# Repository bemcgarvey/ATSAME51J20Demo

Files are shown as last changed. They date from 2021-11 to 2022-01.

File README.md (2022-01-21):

# ATSAME51J20Demo
 
## A demonstartion board for the ATSAME51J20 microcontroller.  Includes firmware projects to demonstrate many modules and features.  
  
### There is sample firmware for:
* Basic gpio and interrupts
* Event system
* DMA
* Full speed USB
* SD Card
* USB bootloader and file system boot loader (sd card)
* USB CDC device
* and more

### All firmware is built in MPLabX with MPLab Harmony 3 and the XC32 compiler.  
### Schematic and PCB were made with KiCAD

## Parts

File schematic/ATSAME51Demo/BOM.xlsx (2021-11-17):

Reference | Quantity | Value | Footprint
C1 C4 C5 C6 C8 C10 C12 | 7 | 100n | Capacitor_SMD:C_0402_1005Metric
C11 | 1 | 4.7uF | Capacitor_SMD:C_0603_1608Metric
C15 | 1 | 10uF | Capacitor_SMD:C_0603_1608Metric
C14 C16 | 2 | 100n | Capacitor_SMD:C_0603_1608Metric
C17 | 1 | 220n | Capacitor_SMD:C_0603_1608Metric
C2 C3 | 2 | 20p | Capacitor_SMD:C_0603_1608Metric
C7 | 1 | 10uF | Capacitor_SMD:C_0805_2012Metric
C9 | 1 | 22uF | Capacitor_SMD:C_0603_1608Metric
D1 | 1 | Red | LED_SMD:LED_0603_1608Metric
D2 | 1 | Red | LED_SMD:LED_0805_2012Metric
D3 D4 | 2 | MBR0520LT | Diode_SMD:D_SOD-123
D5 | 1 | Yellow | LED_SMD:LED_0805_2012Metric
D6 | 1 | Blue | LED_SMD:LED_0805_2012Metric
D7 | 1 | Green | LED_SMD:LED_0805_2012Metric
D8 | 1 | Green | LED_SMD:LED_0603_1608Metric
D9 | 1 | Yellow | LED_SMD:LED_0603_1608Metric
IC1 | 1 | ATSAME51J20A-AU | SamacSys_Parts:QFP50P1200X1200X120-64N
IC2 | 1 | AZ1117IH-3.3TRG1 | SamacSys_Parts:SOT230P700X180-4N
IC3 | 1 | MCP2221-I_SL | SamacSys_Parts:SOIC127P600X175-14N
J1 | 1 | Barrel_Jack_Switch | Connector_BarrelJack:BarrelJack_Wuerth_6941xx301002
J10 J15 | 2 | Conn_02x06_Odd_Even | Connector_PinHeader_2.54mm:PinHeader_2x06_P2.54mm_Vertical
J11 J16 | 2 | Conn_02x07_Odd_Even | Connector_PinHeader_2.54mm:PinHeader_2x07_P2.54mm_Vertical
J13 | 1 | Conn_01x08 | Connector_PinHeader_2.54mm:PinHeader_1x08_P2.54mm_Horizontal
J14 | 1 | Conn_02x08_Odd_Even | Connector_PinHeader_2.54mm:PinHeader_2x08_P2.54mm_Vertical
J2 | 1 | Power | Connector_PinHeader_2.54mm:PinHeader_2x03_P2.54mm_Vertical
J3 J6 J12 J17 | 4 | Conn_01x02 | Connector_PinHeader_2.54mm:PinHeader_1x02_P2.54mm_Vertical
J4 | 1 | USB_B_Micro | Connector_USB:USB_Micro-B_Amphenol_10104110_Horizontal
J5 | 1 | USB_B_Mini | Connector_USB:USB_Mini-B_Wuerth_65100516121_Horizontal
J7 J8 | 2 | Conn_02x02_Odd_Even | Connector_PinHeader_2.54mm:PinHeader_2x02_P2.54mm_Vertical
J9 | 1 | Micro SD Card | SamacSys_Parts:MEM20750014001A
L1 | 1 | 470R | Inductor_SMD:L_0603_1608Metric
L2 | 1 | 10uH | Inductor_SMD:L_0603_1608Metric
R1 R9 R10 R12 R15 | 5 | 100k | Resistor_SMD:R_0603_1608Metric
R11 R14 | 2 | 4k7 | Resistor_SMD:R_0603_1608Metric
R13 R16 R17 R18 | 4 | 10k | Resistor_SMD:R_0603_1608Metric
R2 R5 R6 R8 R19 R20 | 6 | 220R | Resistor_SMD:R_0603_1608Metric
R3 | 1 | 15k | Resistor_SMD:R_0603_1608Metric
R4 | 1 | 22k | Resistor_SMD:R_0603_1608Metric
R7 | 1 | 62R | Resistor_SMD:R_0603_1608Metric
SW1 | 1 | SW_MEC_5E | SamacSys_Parts:PTS647SK38SMTR2LFS
SW2 SW3 | 2 | SW_MEC_5E | SamacSys_Parts:FSM16JH
X1 | 1 | 12 MHz | SamacSys_Parts:ASTMUPCE3312000MHZLJET
X2 | 1 | 32.768 kHz 12.5 pF | SamacSys_Parts:CM9VT1A

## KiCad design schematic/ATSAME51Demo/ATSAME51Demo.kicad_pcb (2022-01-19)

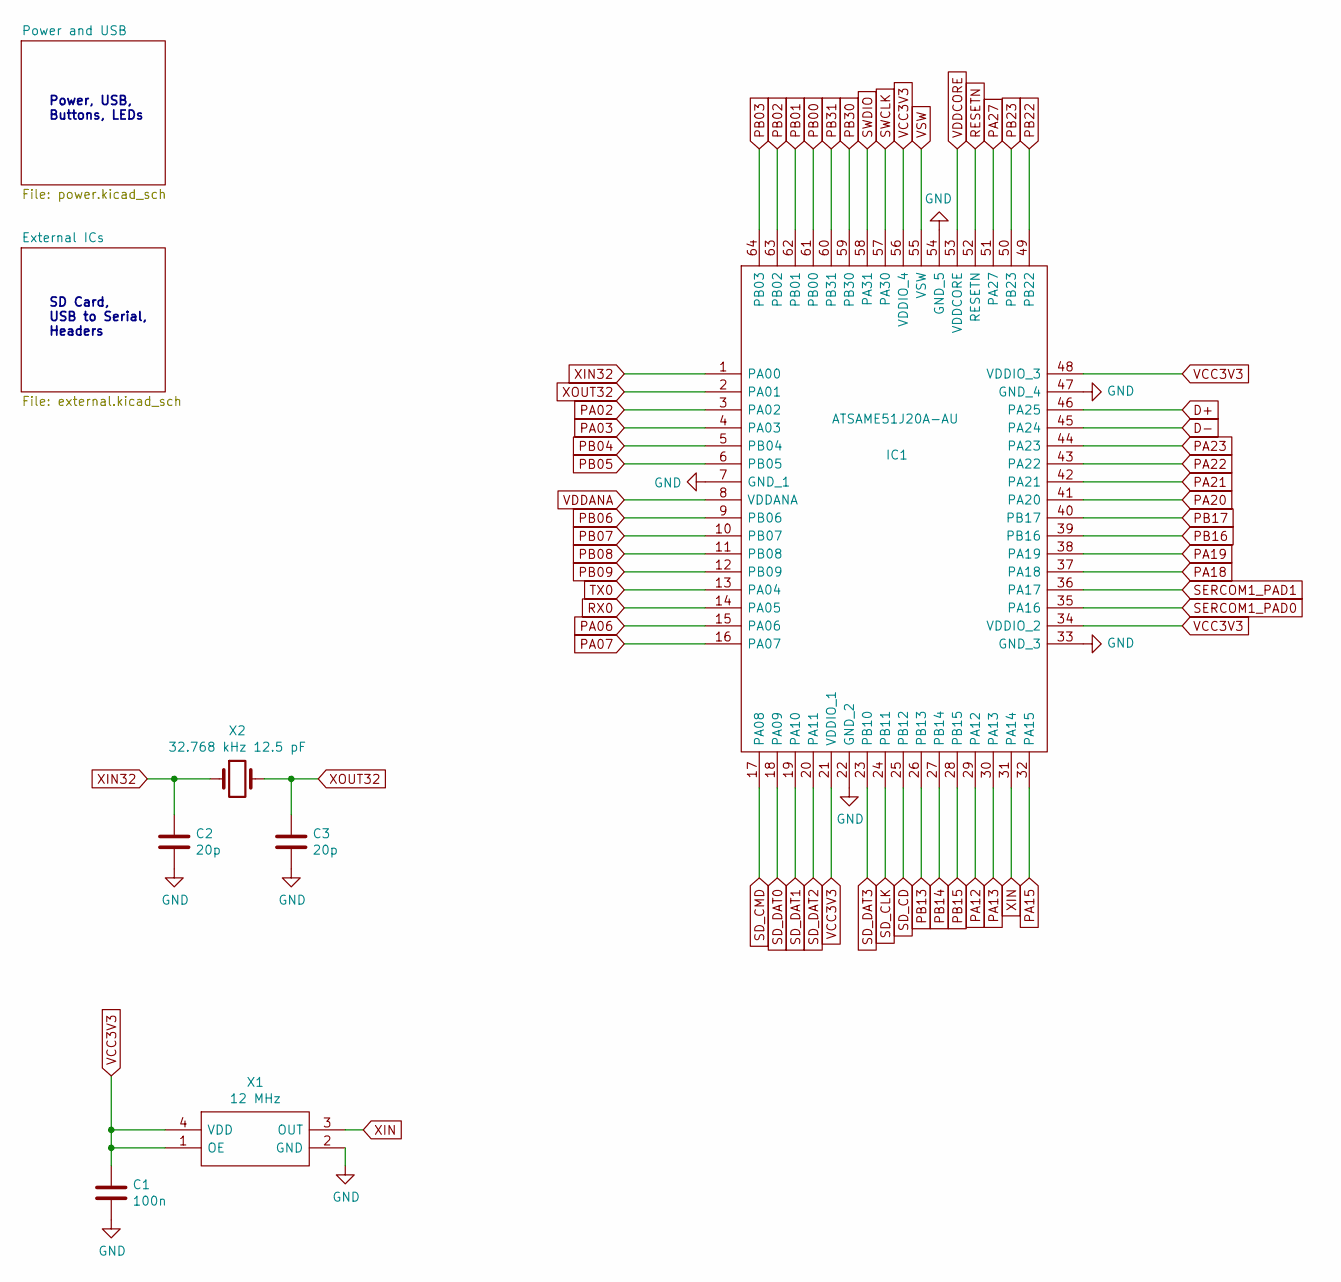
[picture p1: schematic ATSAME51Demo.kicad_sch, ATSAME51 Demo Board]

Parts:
C1: 100n; C_0402_1005Metric
C2, C3: 20p; C_0603_1608Metric
IC1: ATSAME51J20A-AU; QFP50P1200X1200X120-64N; Mouser Part Number 556-ATSAME51J20A-AU
X1: 12 MHz; ASTMUPCE3312000MHZLJET; Mouser Part Number 815-UPCE3312LJET
X2: 32.768 kHz 12.5 pF; CM9VT1A

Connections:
D+: IC1.46 (PA25); also elsewhere on the board
D-: IC1.45 (PA24); also elsewhere on the board
GND: C1.2, C2.2, C3.2, IC1.7 (GND_1), IC1.22 (GND_2), IC1.33 (GND_3), IC1.47 (GND_4), IC1.54 (GND_5), X1.2 (GND); also elsewhere on the board
PA02: IC1.3 (PA02); also elsewhere on the board
PA03: IC1.4 (PA03); also elsewhere on the board
PA06: IC1.15 (PA06); also elsewhere on the board
PA07: IC1.16 (PA07); also elsewhere on the board
PA12: IC1.29 (PA12); also elsewhere on the board
PA13: IC1.30 (PA13); also elsewhere on the board
PA15: IC1.32 (PA15); also elsewhere on the board
PA18: IC1.37 (PA18); also elsewhere on the board
PA19: IC1.38 (PA19); also elsewhere on the board
PA20: IC1.41 (PA20); also elsewhere on the board
PA21: IC1.42 (PA21); also elsewhere on the board
PA22: IC1.43 (PA22); also elsewhere on the board
PA23: IC1.44 (PA23); also elsewhere on the board
PA27: IC1.51 (PA27); also elsewhere on the board
PB00: IC1.61 (PB00); also elsewhere on the board
PB01: IC1.62 (PB01); also elsewhere on the board
PB02: IC1.63 (PB02); also elsewhere on the board
PB03: IC1.64 (PB03); also elsewhere on the board
PB04: IC1.5 (PB04); also elsewhere on the board
PB05: IC1.6 (PB05); also elsewhere on the board
PB06: IC1.9 (PB06); also elsewhere on the board
PB07: IC1.10 (PB07); also elsewhere on the board
PB08: IC1.11 (PB08); also elsewhere on the board
PB09: IC1.12 (PB09); also elsewhere on the board
PB13: IC1.26 (PB13); also elsewhere on the board
PB14: IC1.27 (PB14); also elsewhere on the board
PB15: IC1.28 (PB15); also elsewhere on the board
PB16: IC1.39 (PB16); also elsewhere on the board
PB17: IC1.40 (PB17); also elsewhere on the board
PB22: IC1.49 (PB22); also elsewhere on the board
PB23: IC1.50 (PB23); also elsewhere on the board
PB30: IC1.59 (PB30); also elsewhere on the board
PB31: IC1.60 (PB31); also elsewhere on the board
RESETN: IC1.52 (RESETN); also elsewhere on the board
RX0: IC1.14 (PA05); also elsewhere on the board
SD_CD: IC1.25 (PB12); also elsewhere on the board
SD_CLK: IC1.24 (PB11); also elsewhere on the board
SD_CMD: IC1.17 (PA08); also elsewhere on the board
SD_DAT0: IC1.18 (PA09); also elsewhere on the board
SD_DAT1: IC1.19 (PA10); also elsewhere on the board
SD_DAT2: IC1.20 (PA11); also elsewhere on the board
SD_DAT3: IC1.23 (PB10); also elsewhere on the board
SERCOM1_PAD0: IC1.35 (PA16); also elsewhere on the board
SERCOM1_PAD1: IC1.36 (PA17); also elsewhere on the board
SWCLK: IC1.57 (PA30); also elsewhere on the board
SWDIO: IC1.58 (PA31); also elsewhere on the board
TX0: IC1.13 (PA04); also elsewhere on the board
VCC3V3: C1.1, IC1.21 (VDDIO_1), IC1.34 (VDDIO_2), IC1.48 (VDDIO_3), IC1.56 (VDDIO_4), X1.1 (OE), X1.4 (VDD); also elsewhere on the board
VDDANA: IC1.8 (VDDANA); also elsewhere on the board
VDDCORE: IC1.53 (VDDCORE); also elsewhere on the board
VSW: IC1.55 (VSW); also elsewhere on the board
XIN: IC1.31 (PA14), X1.3 (OUT)
XIN32: C2.1, IC1.1 (PA00), X2.1
XOUT32: C3.1, IC1.2 (PA01), X2.2

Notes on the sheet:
Power, USB, Buttons, LEDs
SD Card, USB to Serial, Headers

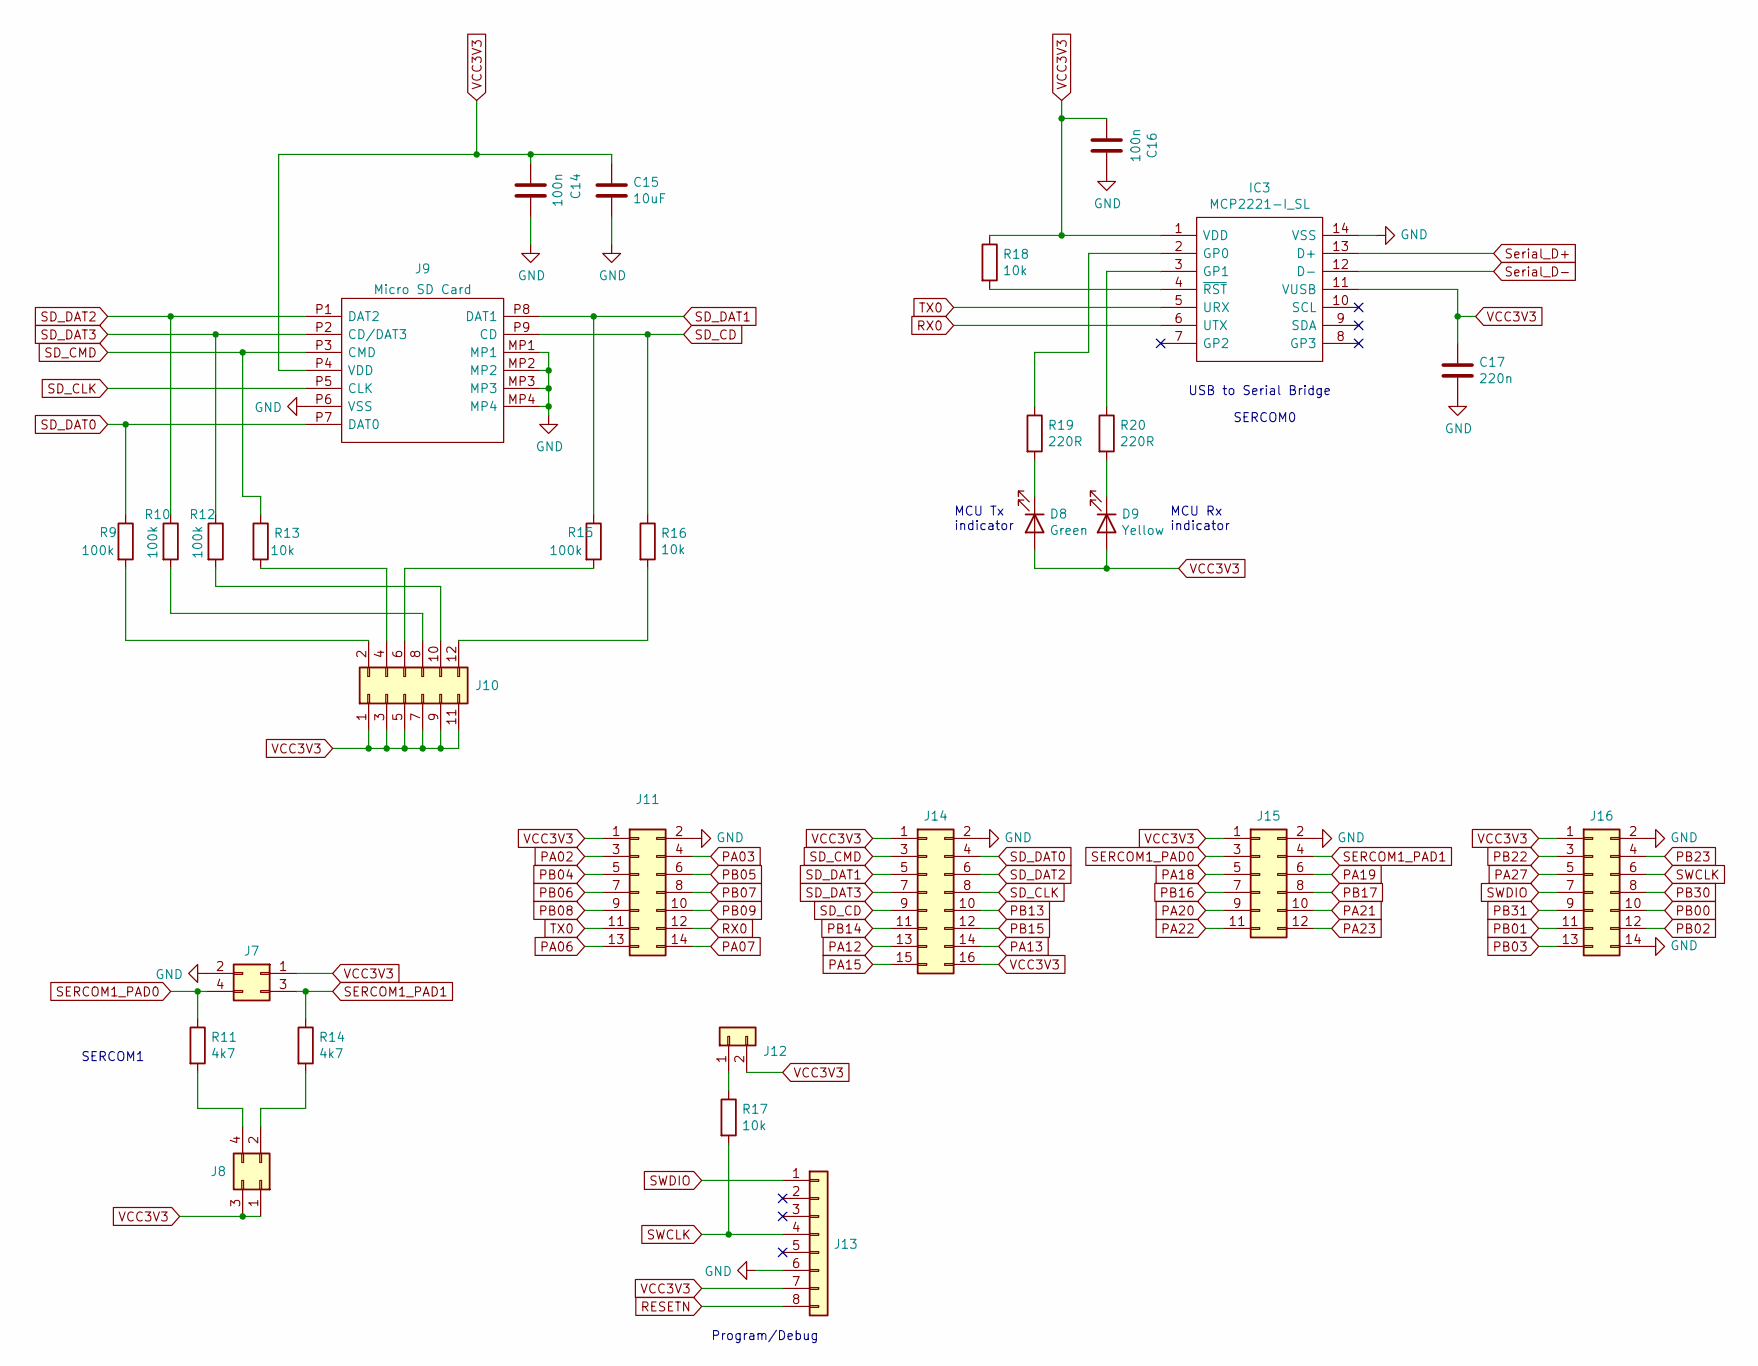
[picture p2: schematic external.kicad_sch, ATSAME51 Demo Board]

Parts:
C14, C16: 100n; C_0603_1608Metric
C15: 10uF; C_0603_1608Metric
C17: 220n; C_0603_1608Metric
D8: Green; LED_0603_1608Metric
D9: Yellow; LED_0603_1608Metric
IC3: MCP2221-I_SL; SOIC127P600X175-14N; Mouser Part Number 579-MCP2221-I/SL
J7, J8: Conn_02x02_Odd_Even; PinHeader_2x02_P2.54mm_Vertical
J9: Micro SD Card; MEM20750014001A; Mouser Part Number 640-MEM20750014001A
J10, J15: Conn_02x06_Odd_Even; PinHeader_2x06_P2.54mm_Vertical
J11, J16: Conn_02x07_Odd_Even; PinHeader_2x07_P2.54mm_Vertical
J12: Conn_01x02; PinHeader_1x02_P2.54mm_Vertical
J13: Conn_01x08; PinHeader_1x08_P2.54mm_Horizontal
J14: Conn_02x08_Odd_Even; PinHeader_2x08_P2.54mm_Vertical
R9, R10, R12, R15: 100k; R_0603_1608Metric
R11, R14: 4k7; R_0603_1608Metric
R13, R16, R17, R18: 10k; R_0603_1608Metric
R19, R20: 220R; R_0603_1608Metric

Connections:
GND: C14.1, C15.2, C16.1, C17.2, IC3.14 (VSS), J7.2, J9.MP1, J9.MP2, J9.MP3, J9.MP4, J9.P6 (VSS), J11.2, J13.6, J14.2, J15.2, J16.2, J16.14; also elsewhere on the board
unnamed: D8.1 (K), R19.2
unnamed: D9.1 (K), R20.2
unnamed: IC3.2 (GP0), R19.1
unnamed: IC3.3 (GP1), R20.1
unnamed: IC3.4 (~RST), R18.2
unnamed: J8.2, R14.2
unnamed: J8.4, R11.2
unnamed: J10.2, R9.2
unnamed: J10.4, R13.2
unnamed: J10.6, R15.2
unnamed: J10.8, R10.2
unnamed: J10.10, R12.2
unnamed: J10.12, R16.2
unnamed: J12.1, R17.1
PA02: J11.3; also elsewhere on the board
PA03: J11.4; also elsewhere on the board
PA06: J11.13; also elsewhere on the board
PA07: J11.14; also elsewhere on the board
PA12: J14.13; also elsewhere on the board
PA13: J14.14; also elsewhere on the board
PA15: J14.15; also elsewhere on the board
PA18: J15.5; also elsewhere on the board
PA19: J15.6; also elsewhere on the board
PA20: J15.9; also elsewhere on the board
PA21: J15.10; also elsewhere on the board
PA22: J15.11; also elsewhere on the board
PA23: J15.12; also elsewhere on the board
PA27: J16.5; also elsewhere on the board
PB00: J16.10; also elsewhere on the board
PB01: J16.11; also elsewhere on the board
PB02: J16.12; also elsewhere on the board
PB03: J16.13; also elsewhere on the board
PB04: J11.5; also elsewhere on the board
PB05: J11.6; also elsewhere on the board
PB06: J11.7; also elsewhere on the board
PB07: J11.8; also elsewhere on the board
PB08: J11.9; also elsewhere on the board
PB09: J11.10; also elsewhere on the board
PB13: J14.10; also elsewhere on the board
PB14: J14.11; also elsewhere on the board
PB15: J14.12; also elsewhere on the board
PB16: J15.7; also elsewhere on the board
PB17: J15.8; also elsewhere on the board
PB22: J16.3; also elsewhere on the board
PB23: J16.4; also elsewhere on the board
PB30: J16.8; also elsewhere on the board
PB31: J16.9; also elsewhere on the board
RESETN: J13.8; also elsewhere on the board
RX0: IC3.6 (UTX), J11.12; also elsewhere on the board
SD_CD: J9.P9 (CD), J14.9, R16.1; also elsewhere on the board
SD_CLK: J9.P5 (CLK), J14.8; also elsewhere on the board
SD_CMD: J9.P3 (CMD), J14.3, R13.1; also elsewhere on the board
SD_DAT0: J9.P7 (DAT0), J14.4, R9.1; also elsewhere on the board
SD_DAT1: J9.P8 (DAT1), J14.5, R15.1; also elsewhere on the board
SD_DAT2: J9.P1 (DAT2), J14.6, R10.1; also elsewhere on the board
SD_DAT3: J9.P2 (CD/DAT3), J14.7, R12.1; also elsewhere on the board
SERCOM1_PAD0: J7.4, J15.3, R11.1; also elsewhere on the board
SERCOM1_PAD1: J7.3, J15.4, R14.1; also elsewhere on the board
SWCLK: J13.4, J16.6, R17.2; also elsewhere on the board
SWDIO: J13.1, J16.7; also elsewhere on the board
Serial_D+: IC3.13 (D+); also elsewhere on the board
Serial_D-: IC3.12 (D-); also elsewhere on the board
TX0: IC3.5 (URX), J11.11; also elsewhere on the board
VCC3V3: C14.2, C15.1, C16.2, C17.1, D8.2 (A), D9.2 (A), IC3.1 (VDD), IC3.11 (VUSB), J7.1, J8.1, J8.3, J9.P4 (VDD), J10.1, J10.3, J10.5, J10.7, J10.9, J10.11, J11.1, J12.2, J13.7, J14.1, J14.16, J15.1, J16.1, R18.1; also elsewhere on the board

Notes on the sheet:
MCU Rx indicator
SERCOM1
Program/Debug
SERCOM0
MCU Tx indicator
USB to Serial Bridge

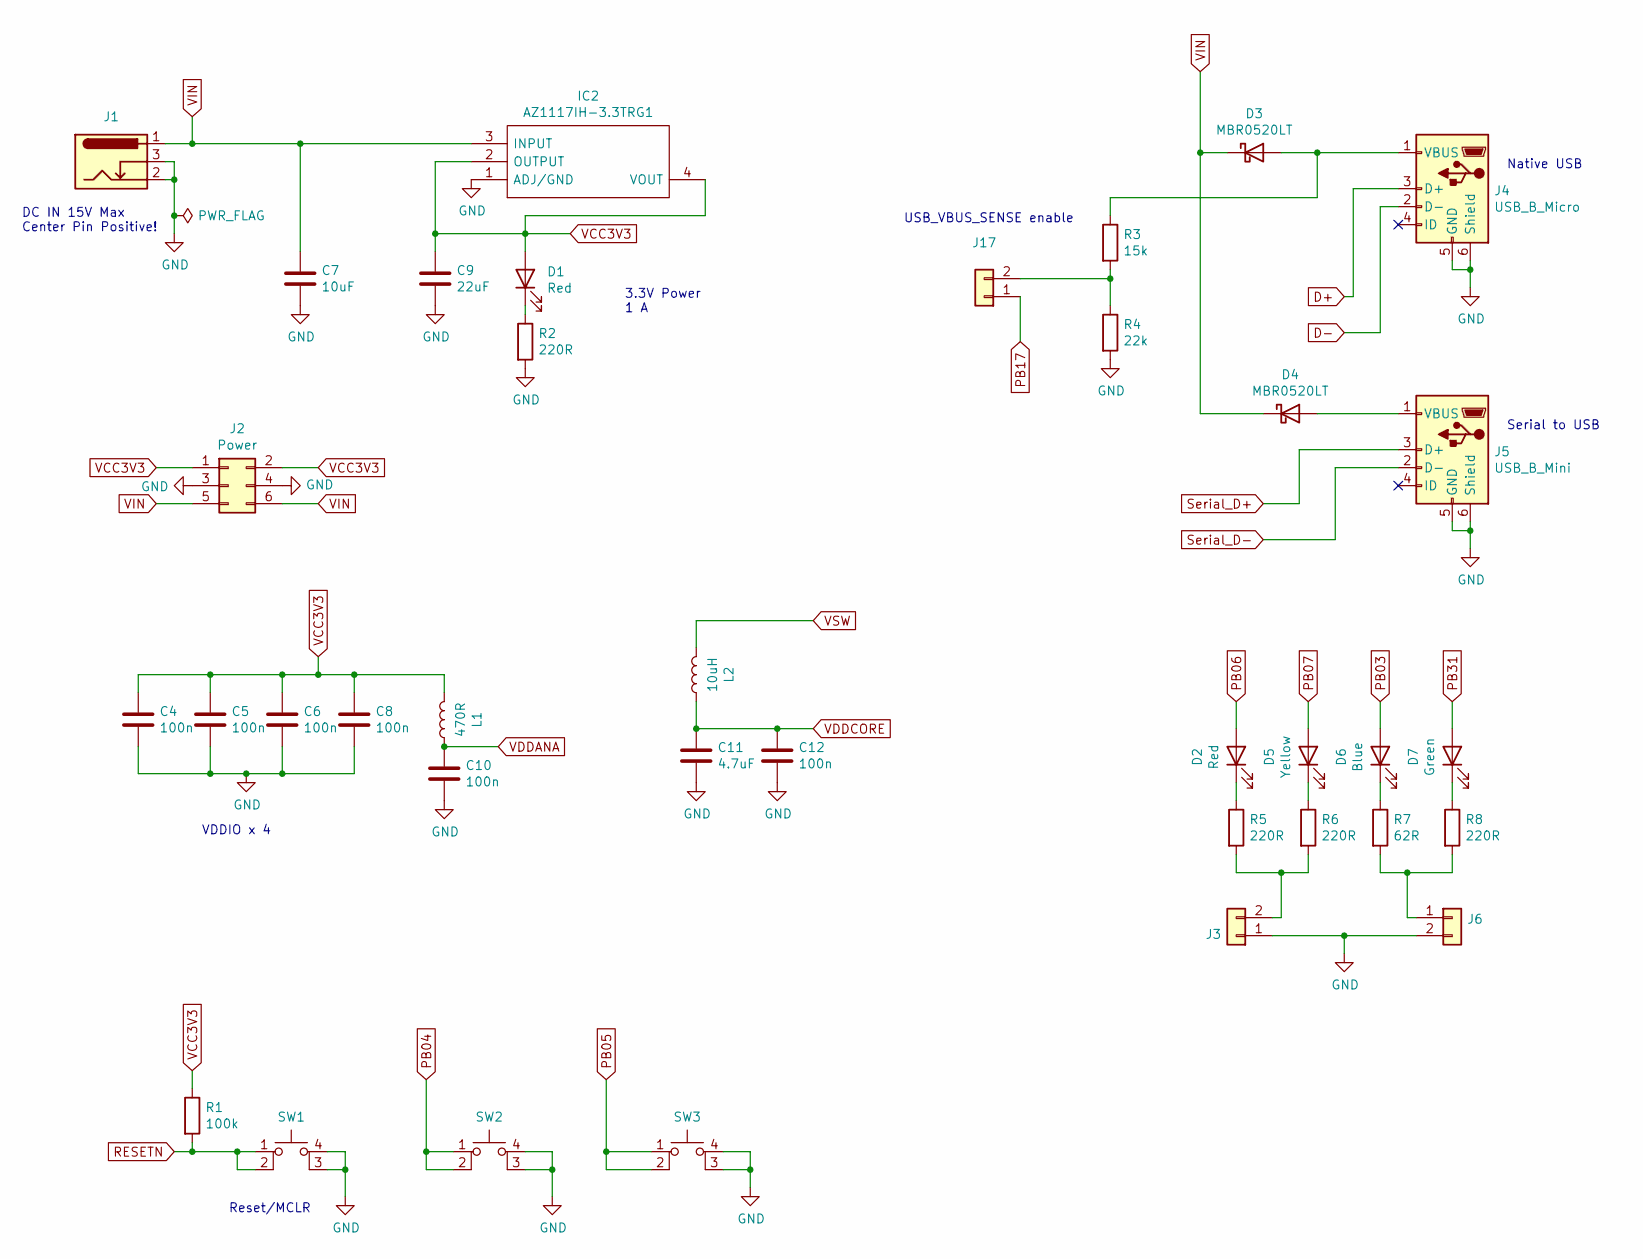
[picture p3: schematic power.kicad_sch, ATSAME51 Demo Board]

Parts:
C4, C5, C6, C8, C10, C12: 100n; C_0402_1005Metric
C7: 10uF; C_0805_2012Metric
C9: 22uF; C_0603_1608Metric
C11: 4.7uF; C_0603_1608Metric
D1: Red; LED_0603_1608Metric
D2: Red; LED_0805_2012Metric
D3, D4: MBR0520LT; D_SOD-123
D5: Yellow; LED_0805_2012Metric
D6: Blue; LED_0805_2012Metric
D7: Green; LED_0805_2012Metric
IC2: AZ1117IH-3.3TRG1; SOT230P700X180-4N; Mouser Part Number 621-AZ1117IH-3.3TRG1
J1: Barrel_Jack_Switch; BarrelJack_Wuerth_6941xx301002
J2: Power; PinHeader_2x03_P2.54mm_Vertical
J3, J6, J17: Conn_01x02; PinHeader_1x02_P2.54mm_Vertical
J4: USB_B_Micro; USB_Micro-B_Amphenol_10104110_Horizontal
J5: USB_B_Mini; USB_Mini-B_Wuerth_65100516121_Horizontal
L1: 470R; L_0603_1608Metric
L2: 10uH; L_0603_1608Metric
R1: 100k; R_0603_1608Metric
R2, R5, R6, R8: 220R; R_0603_1608Metric
R3: 15k; R_0603_1608Metric
R4: 22k; R_0603_1608Metric
R7: 62R; R_0603_1608Metric
SW1: SW_MEC_5E; PTS647SK38SMTR2LFS
SW2, SW3: SW_MEC_5E; FSM16JH

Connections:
D+: J4.3 (D+); also elsewhere on the board
D-: J4.2 (D-); also elsewhere on the board
GND: C4.2, C5.2, C6.2, C7.2, C8.2, C9.2, C10.2, C11.2, C12.2, IC2.1 (ADJ/GND), J1.2, J1.3, J2.3, J2.4, J3.1, J4.5 (GND), J4.6 (Shield), J5.5 (GND), J5.6 (Shield), J6.2, R2.2, R4.2, SW1.3 (K), SW1.4 (A), SW2.3 (K), SW2.4 (A), SW3.3 (K), SW3.4 (A); also elsewhere on the board
unnamed: D1.1 (K), R2.1
unnamed: D2.1 (K), R5.1
unnamed: D3.2 (A), J4.1 (VBUS), R3.1
unnamed: D4.2 (A), J5.1 (VBUS)
unnamed: D5.1 (K), R6.1
unnamed: D6.1 (K), R7.1
unnamed: D7.1 (K), R8.1
unnamed: J3.2, R5.2, R6.2
unnamed: J6.1, R7.2, R8.2
unnamed: J17.2, R3.2, R4.1
PB03: D6.2 (A); also elsewhere on the board
PB04: SW2.1, SW2.2; also elsewhere on the board
PB05: SW3.1, SW3.2; also elsewhere on the board
PB06: D2.2 (A); also elsewhere on the board
PB07: D5.2 (A); also elsewhere on the board
PB17: J17.1; also elsewhere on the board
PB31: D7.2 (A); also elsewhere on the board
RESETN: R1.2, SW1.1, SW1.2; also elsewhere on the board
Serial_D+: J5.3 (D+); also elsewhere on the board
Serial_D-: J5.2 (D-); also elsewhere on the board
VCC3V3: C4.1, C5.1, C6.1, C8.1, C9.1, D1.2 (A), IC2.2 (OUTPUT), IC2.4 (VOUT), J2.1, J2.2, L1.2, R1.1; also elsewhere on the board
VDDANA: C10.1, L1.1; also elsewhere on the board
VDDCORE: C11.1, C12.1, L2.1; also elsewhere on the board
VIN: C7.1, D3.1 (K), D4.1 (K), IC2.3 (INPUT), J1.1, J2.5, J2.6
VSW: L2.2; also elsewhere on the board

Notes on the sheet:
Serial to USB
USB_VBUS_SENSE enable
VDDIO x 4
DC IN 15V Max Center Pin Positive!
Native USB
3.3V Power 1 A
Reset/MCLR

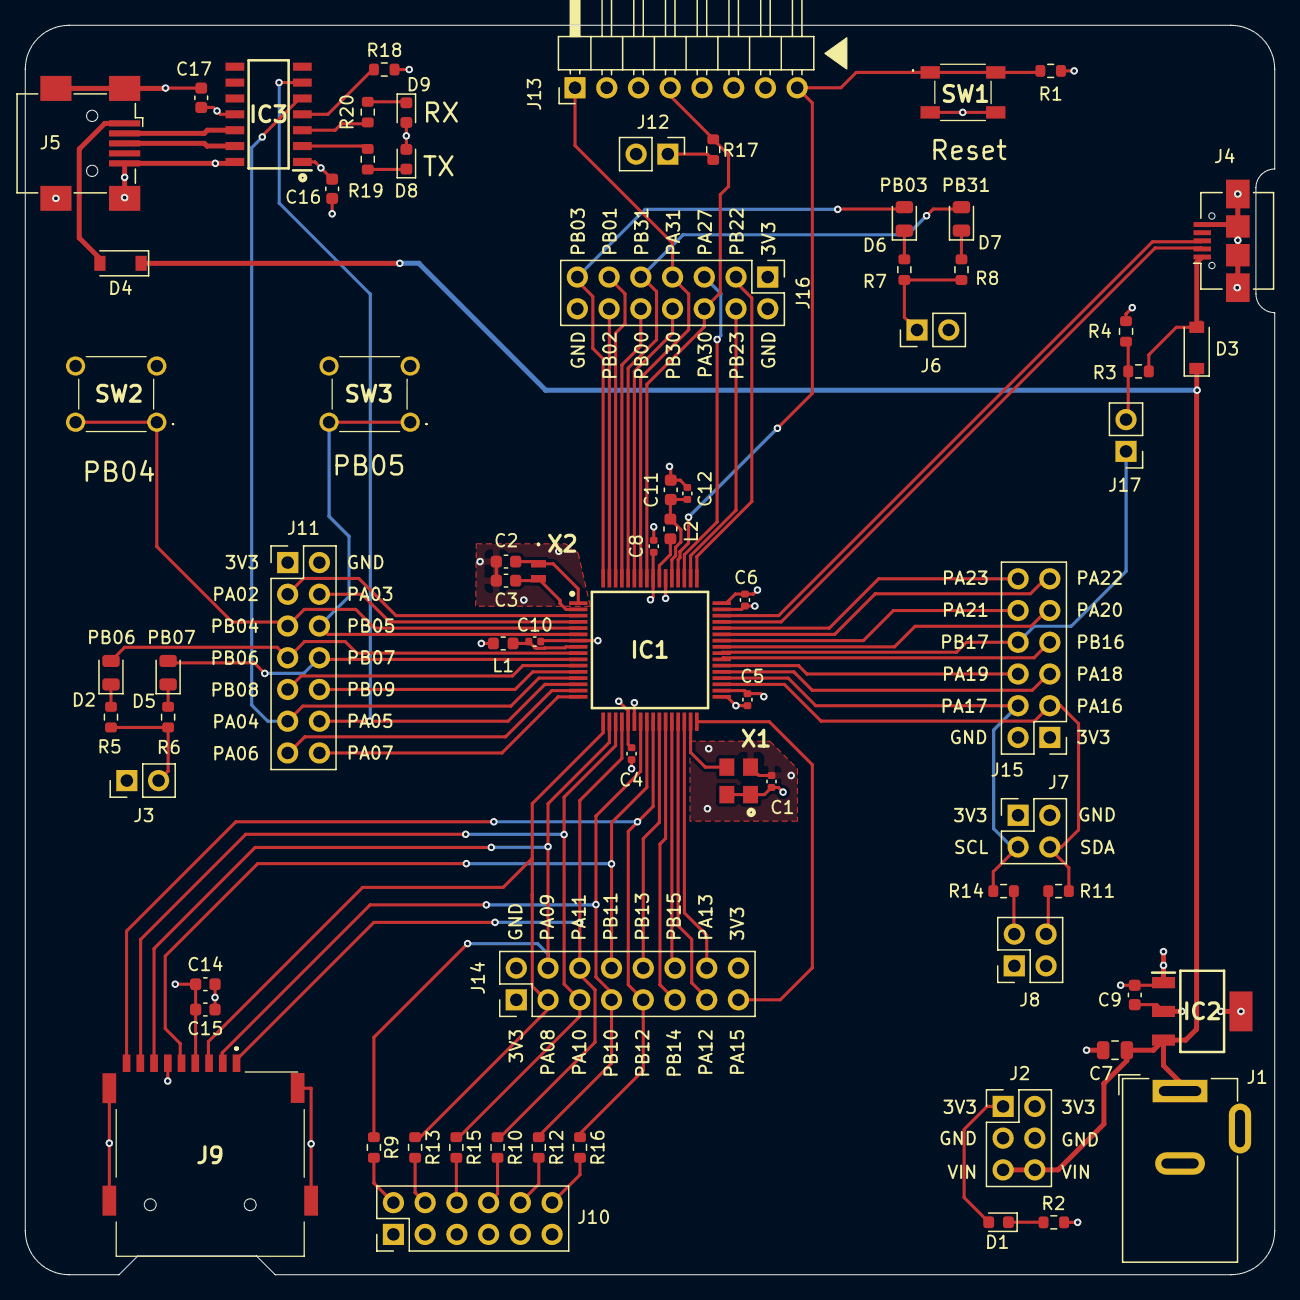
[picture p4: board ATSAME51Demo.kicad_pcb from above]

Board: 4 copper layers, 100.0 x 100.0 mm, 72 parts (0 on the bottom side), 84 nets.

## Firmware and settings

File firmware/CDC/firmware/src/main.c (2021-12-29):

/*******************************************************************************
  Main Source File

  Company:
    Microchip Technology Inc.

  File Name:
    main.c

  Summary:
    This file contains the "main" function for a project.

  Description:
    This file contains the "main" function for a project.  The
    "main" function calls the "SYS_Initialize" function to initialize the state
    machines of all modules in the system
 *******************************************************************************/

// *****************************************************************************
// *****************************************************************************
// Section: Included Files
// *****************************************************************************
// *****************************************************************************

#include <stddef.h>                     // Defines NULL
#include <stdbool.h>                    // Defines true
#include <stdlib.h>                     // Defines EXIT_FAILURE
#include "definitions.h"                // SYS function prototypes


// *****************************************************************************
// *****************************************************************************
// Section: Main Entry Point
// *****************************************************************************
// *****************************************************************************

//Notes:  It appears that a composite device requires a serial number in the 
// usb device descriptor.

int main ( void )
{
    /* Initialize all modules */
    SYS_Initialize ( NULL );

    while ( true )
    {
        /* Maintain state machines of all polled MPLAB Harmony modules. */
        SYS_Tasks ( );
    }

    /* Execution should not come here during normal operation */

    return ( EXIT_FAILURE );
}


/*******************************************************************************
 End of File
*/

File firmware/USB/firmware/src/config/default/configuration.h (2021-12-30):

/*******************************************************************************
  System Configuration Header

  File Name:
    configuration.h

  Summary:
    Build-time configuration header for the system defined by this project.

  Description:
    An MPLAB Project may have multiple configurations.  This file defines the
    build-time options for a single configuration.

  Remarks:
    This configuration header must not define any prototypes or data
    definitions (or include any files that do).  It only provides macro
    definitions for build-time configuration options

*******************************************************************************/

// DOM-IGNORE-BEGIN
/*******************************************************************************
* Copyright (C) 2018 Microchip Technology Inc. and its subsidiaries.
*
* Subject to your compliance with these terms, you may use Microchip software
* and any derivatives exclusively with Microchip products. It is your
* responsibility to comply with third party license terms applicable to your
* use of third party software (including open source software) that may
* accompany Microchip software.
*
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
* IN NO EVENT WILL MICROCHIP BE LIABLE FOR ANY INDIRECT, SPECIAL, PUNITIVE,
* INCIDENTAL OR CONSEQUENTIAL LOSS, DAMAGE, COST OR EXPENSE OF ANY KIND
* WHATSOEVER RELATED TO THE SOFTWARE, HOWEVER CAUSED, EVEN IF MICROCHIP HAS
* BEEN ADVISED OF THE POSSIBILITY OR THE DAMAGES ARE FORESEEABLE. TO THE
* FULLEST EXTENT ALLOWED BY LAW, MICROCHIP'S TOTAL LIABILITY ON ALL CLAIMS IN
* ANY WAY RELATED TO THIS SOFTWARE WILL NOT EXCEED THE AMOUNT OF FEES, IF ANY,
* THAT YOU HAVE PAID DIRECTLY TO MICROCHIP FOR THIS SOFTWARE.
*******************************************************************************/
// DOM-IGNORE-END

#ifndef CONFIGURATION_H
#define CONFIGURATION_H

// *****************************************************************************
// *****************************************************************************
// Section: Included Files
// *****************************************************************************
// *****************************************************************************
/*  This section Includes other configuration headers necessary to completely
    define this configuration.
*/

#include "user.h"
#include "device.h"

// DOM-IGNORE-BEGIN
#ifdef __cplusplus  // Provide C++ Compatibility

extern "C" {

#endif
// DOM-IGNORE-END

// *****************************************************************************
// *****************************************************************************
// Section: System Configuration
// *****************************************************************************
// *****************************************************************************



// *****************************************************************************
// *****************************************************************************
// Section: System Service Configuration
// *****************************************************************************
// *****************************************************************************
/* TIME System Service Configuration Options */
#define SYS_TIME_INDEX_0                            (0)
#define SYS_TIME_MAX_TIMERS                         (5)
#define SYS_TIME_HW_COUNTER_WIDTH                   (16)
#define SYS_TIME_HW_COUNTER_PERIOD                  (0xFFFFU)
#define SYS_TIME_HW_COUNTER_HALF_PERIOD             (SYS_TIME_HW_COUNTER_PERIOD>>1)
#define SYS_TIME_CPU_CLOCK_FREQUENCY                (120000000)
#define SYS_TIME_COMPARE_UPDATE_EXECUTION_CYCLES    (188)



// *****************************************************************************
// *****************************************************************************
// Section: Driver Configuration
// *****************************************************************************
// *****************************************************************************
/* SDMMC Driver Global Configuration Options */
#define DRV_SDMMC_INSTANCES_NUMBER                       1

/* Memory Driver Global Configuration Options */
#define DRV_MEMORY_INSTANCES_NUMBER          1

/* Memory Driver Instance 0 Configuration */
#define DRV_MEMORY_INDEX_0                   0
#define DRV_MEMORY_CLIENTS_NUMBER_IDX0       1
#define DRV_MEMORY_BUFFER_QUEUE_SIZE_IDX0    1
#define DRV_MEMORY_DEVICE_START_ADDRESS      0x80000
#define DRV_MEMORY_DEVICE_MEDIA_SIZE         512UL
#define DRV_MEMORY_DEVICE_MEDIA_SIZE_BYTES   (DRV_MEMORY_DEVICE_MEDIA_SIZE * 1024)
#define DRV_MEMORY_DEVICE_PROGRAM_SIZE       512
#define DRV_MEMORY_DEVICE_ERASE_SIZE         8192
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

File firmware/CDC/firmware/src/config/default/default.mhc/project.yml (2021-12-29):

files:
- generatedChecksum: F58DB2348A0FCE945652B285010E5F8A
  logicalPath: FreeRTOS/Source
  name: FreeRTOS_tasks.c
  physicalPath: ../../third_party/rtos/FreeRTOS/Source
  security: NON_SECURE
  type: SOURCE
  userChecksum: F58DB2348A0FCE945652B285010E5F8A
- generatedChecksum: null
  logicalPath: ''
  name: app.c
  physicalPath: ../..
  security: NON_SECURE
  type: SOURCE
  userChecksum: null
- generatedChecksum: 8ACE0DEBD82F6829438A4674565451FB
  logicalPath: FreeRTOS/Source
  name: croutine.c
  physicalPath: ../../third_party/rtos/FreeRTOS/Source
  security: NON_SECURE
  type: SOURCE
  userChecksum: 8ACE0DEBD82F6829438A4674565451FB
- generatedChecksum: A963DA487B63E51999A4BC38C048EAC5
  logicalPath: config/default/driver/sdmmc
  name: drv_sdmmc.c
  physicalPath: driver/sdmmc/src
  security: NON_SECURE
  type: SOURCE
  userChecksum: A963DA487B63E51999A4BC38C048EAC5
- generatedChecksum: 941C09024124A4937C0E368A25C140DE
  logicalPath: config/default/driver/usb/usbfsv1/src
  name: drv_usbfsv1.c
  physicalPath: driver/usb/usbfsv1/src
  security: NON_SECURE
  type: SOURCE
  userChecksum: 941C09024124A4937C0E368A25C140DE
- generatedChecksum: DE6B2F7A6193E5F8C2F36196B0B687AC
  logicalPath: config/default/driver/usb/usbfsv1/src
  name: drv_usbfsv1_device.c
  physicalPath: driver/usb/usbfsv1/src
  security: NON_SECURE
  type: SOURCE
  userChecksum: DE6B2F7A6193E5F8C2F36196B0B687AC
- generatedChecksum: B3B5445B14BD9B6A35F1C5B995C9BBF7
  logicalPath: FreeRTOS/Source
  name: event_groups.c
  physicalPath: ../../third_party/rtos/FreeRTOS/Source
  security: NON_SECURE
  type: SOURCE
  userChecksum: B3B5445B14BD9B6A35F1C5B995C9BBF7
- generatedChecksum: 6069C4FD56993BDA3B1FC223DD5BAA4A
  logicalPath: config/default
  name: exceptions.c
  physicalPath: ''
  security: NON_SECURE
  type: SOURCE
  userChecksum: 6069C4FD56993BDA3B1FC223DD5BAA4A
- generatedChecksum: B7DBFD6F500AAD4713403E985EB18EAE
  logicalPath: config/default
  name: freertos_hooks.c
  physicalPath: ''
  security: NON_SECURE
  type: SOURCE
  userChecksum: B7DBFD6F500AAD4713403E985EB18EAE
- generatedChecksum: 972E955D94A63BA89BF6ABD6AADB1023
  logicalPath: FreeRTOS/Source/portable/MemMang
  name: heap_1.c
  physicalPath: ../../third_party/rtos/FreeRTOS/Source/portable/MemMang
  security: NON_SECURE
  type: SOURCE
  userChecksum: 972E955D94A63BA89BF6ABD6AADB1023
- generatedChecksum: 0E286A0AD0CE6292D95B1C50DF7869E8
  logicalPath: config/default
  name: initialization.c
  physicalPath: ''
  security: NON_SECURE
  type: SOURCE
  userChecksum: 0E286A0AD0CE6292D95B1C50DF7869E8
- generatedChecksum: 3922F7597BB28813695FAB64D1E1A421
  logicalPath: config/default
  name: interrupts.c
  physicalPath: ''
  security: NON_SECURE
  type: SOURCE
  userChecksum: 3922F7597BB28813695FAB64D1E1A421
- generatedChecksum: 6513F2461B8F476B68CA73906086047F
  logicalPath: config/default
  name: libc_syscalls.c
  physicalPath: ''
  security: NON_SECURE
  type: SOURCE
  userChecksum: 6513F2461B8F476B68CA73906086047F
- generatedChecksum: 3FEE521CEF14928AE38E7FA9BF6D75E6
  logicalPath: FreeRTOS/Source
  name: list.c
  physicalPath: ../../third_party/rtos/FreeRTOS/Source
  security: NON_SECURE
  type: SOURCE
  userChecksum: 3FEE521CEF14928AE38E7FA9BF6D75E6
- generatedChecksum: null
  logicalPath: ''
  name: main.c
  physicalPath: ../..
  security: NON_SECURE
  type: SOURCE
  userChecksum: null
- generatedChecksum: 8FDD6248506F28B32C4F5FD9AA0D9C6F
  logicalPath: config/default/osal
  name: osal_freertos.c
  physicalPath: osal
  security: NON_SECURE
  type: SOURCE
  userChecksum: 8FDD6248506F28B32C4F5FD9AA0D9C6F
- generatedChecksum: AA26561634BD6EAA358AE1BF5B9691EB
  logicalPath: config/default/peripheral/clock
  name: plib_clock.c
  physicalPath: peripheral/clock
  security: NON_SECURE
  type: SOURCE
  userChecksum: AA26561634BD6EAA358AE1BF5B9691EB
- generatedChecksum: D903E8D9DCBC4107D0AA841E07F653BA
  logicalPath: config/default/peripheral/cmcc
  name: plib_cmcc.c
  physicalPath: peripheral/cmcc
  security: NON_SECURE
  type: SOURCE
  userChecksum: D903E8D9DCBC4107D0AA841E07F653BA
- generatedChecksum: C3ECDED3D6301DB0DE622293ED615D21
  logicalPath: config/default/peripheral/evsys
  name: plib_evsys.c
  physicalPath: peripheral/evsys
  security: NON_SECURE
  type: SOURCE
  userChecksum: C3ECDED3D6301DB0DE622293ED615D21
- generatedChecksum: F2E0F843EFB2E5EE779C5C28BFDB5915
  logicalPath: config/default/peripheral/nvic
  name: plib_nvic.c
  physicalPath: peripheral/nvic
  security: NON_SECURE
  type: SOURCE
  userChecksum: F2E0F843EFB2E5EE779C5C28BFDB5915
- generatedChecksum: 903E0413B53BA9E8980C740E65F59966
  logicalPath: config/default/peripheral/nvmctrl
  name: plib_nvmctrl.c
  physicalPath: peripheral/nvmctrl
  security: NON_SECURE
  type: SOURCE
  userChecksum: 903E0413B53BA9E8980C740E65F59966
- generatedChecksum: 744EF4B29F9A5AB5CD66778F58755F8D
  logicalPath: config/default/peripheral/port
  name: plib_port.c
  physicalPath: peripheral/port
  security: NON_SECURE
  type: SOURCE
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

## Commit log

2021-10-23 Initial commit with KiCad project
    [ATSAME51Demo.kicad_pcb, ATSAME51Demo.sch]
2021-10-25 Schematic first draft
    Still needs footprints
    [ATSAME51Demo.sch, external.sch, power.sch]
2021-10-25 Footprints assigned
    [ATSAME51Demo.sch, external.sch, power.sch]
2021-10-25 PCB design rules set
    4 Layer JLCPCB settings
    [ATSAME51Demo.kicad_pcb]
2021-10-25 Removed USB detect
    [ATSAME51Demo.sch, external.sch, power.sch]
2021-10-26 First draft PCB layout
    Still needs silkscreen cleanup
    [ATSAME51Demo.kicad_pcb, external.sch]
2021-10-26 Front silkscreen done
    [ATSAME51Demo.kicad_pcb]
2021-10-26 Moved SD card back from edge
    Rearranged some connections to improve routing
    [ATSAME51Demo.kicad_pcb, external.sch]
2021-11-10 Adjusted sd card footprint
    [ATSAME51Demo.kicad_pcb]
2021-11-10 Fixed micro usb footprint
    [ATSAME51Demo.kicad_pcb]
2021-11-14 Added USB_VBUS_SENSE
    And other minor improvements
    [ATSAME51Demo.kicad_pcb, external.sch, power.sch]
2021-11-16 Changed leds to 0805
    [ATSAME51Demo.kicad_pcb, power.sch]
2021-11-19 Production gerbers
    [ATSAME51Demo-B_Cu.gbl, ATSAME51Demo-B_Mask.gbs, ATSAME51Demo-B_SilkS.gbo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]
2021-12-18 Added MSD demo
    Restructured firmware directory
    [configuration.h]
2021-12-18 SD card working with MSD
    [configuration.h]
2021-12-18 Changed sd to high speed
    [configuration.h]
2021-12-18 LCD and I2C working
    [configuration.h]
2021-12-22 MSD multiple LUNS working
    [configuration.h]
2021-12-24 Added USB bootloader
    [configuration.h]
2021-12-24 RTC working (and switching regulator)
2021-12-24 Added file system bootloader
    [configuration.h]
2021-12-29 Added DMA demo
2021-12-29 Initial CDC demo
    [configuration.h]
2021-12-29 Switched CDC demo to RTOS
2021-12-29 Added MSD to CDC demo to create composite device
    [configuration.h]
2021-12-30 ADC working
2021-12-30 Setup crystalless usb clock for MSD demo
    [configuration.h]
2022-01-19 Converted to KiCad 6
    [ATSAME51Demo.kicad_pcb, ATSAME51Demo.kicad_sch, ATSAME51Demo.sch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]
